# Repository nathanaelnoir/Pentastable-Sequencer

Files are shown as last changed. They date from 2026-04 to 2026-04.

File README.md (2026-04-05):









# Pentastable Sequencer 

# Pentastable Sequencer is a 5-step Eurorack sequencer inspired by the Buchla Sound Easel.

## Contents

- Overview
- Features
- Build & assembly notes
- Testing
- License & contributing

## Overview

This repository contains the KiCad 9 design files for Pentastable Sequencer. The module is built around an `Arduino Nano` with a `TL072` handling the analog output stage. Five pots set the sequence voltages, five LEDs show the active step, `TRIG IN` and `RESET IN` let the module sync to the rack, and `CV OUT` plus `TRIG OUT` bring the sequence back out.

The front panel also carries five step toggles, one `TEMPO` pot for the internal clock, one extra pot in the CV output section, and two center-off mode switches wired as `3st / off / 5st` and `FWD / off / RND_TIE`.

Revision in the KiCad title block is `v1.0`, dated `2026-03-13`.

## Features

- 5-step sequencer built around `Arduino Nano v3.x` and `TL072`.
- Five 10 k step pots: `CV1` to `CV5`.
- Five step LEDs for position indication.
- Internal clock with dedicated `TEMPO` control.
- External `TRIG IN` and `RESET IN`.
- Separate `CV OUT` and `TRIG OUT`.
- Five panel toggles tied to the individual stage outputs: `OUT1` to `OUT5`.
- Center-off mode switches for stage count (`3st` / `5st`) and playback behavior (`FWD` / `RND_TIE`).
- Eurorack power sheet using `+12V`, `-12V`, `+5V`, and `GND` on a 16-pin IDC connector.
- Mixed build with SMD passives and ICs plus through-hole panel hardware.

## Build & assembly notes

- Check `A1` orientation and header alignment before soldering the `Arduino Nano`.
- Check `U1` orientation before soldering the `TL072`.
- Double-check the Eurorack power header orientation before first power-up.
- The panel hardware count is not small: four 3.5 mm jacks, seven potentiometers, seven toggle switches, and five LEDs.
- `SW6` and `SW7` are center-off switches. The schematic note calls this out explicitly because the symbol can look misleading if you read it too quickly.
- The output side uses a buffered CV stage around `U1`, `R7`, `R8`, and the extra panel pot. If you change values there, expect the CV output behavior to change with it.

## Testing

1. Program the `Arduino Nano` with the matching firmware before expecting the module to run. This repository does not include that firmware.
2. Power the module from a current-limited Eurorack supply and verify `+12V`, `-12V`, `+5V`, and `GND` first.
3. Turn the internal `TEMPO` control and confirm the step LEDs advance.
4. Feed a pulse into `TRIG IN` and confirm the sequencer advances from the external trigger.
5. Trigger `RESET IN` and confirm the sequence returns to the first stage.
6. Check `CV OUT` and `TRIG OUT` with a scope or a known-good downstream module.

## License & contributing

No `LICENSE` file has been added to this repository yet. Until that changes, assume the design is shared for reference and not under an explicit open-source license.

$$ \huge \prod_{\star}^5 $$

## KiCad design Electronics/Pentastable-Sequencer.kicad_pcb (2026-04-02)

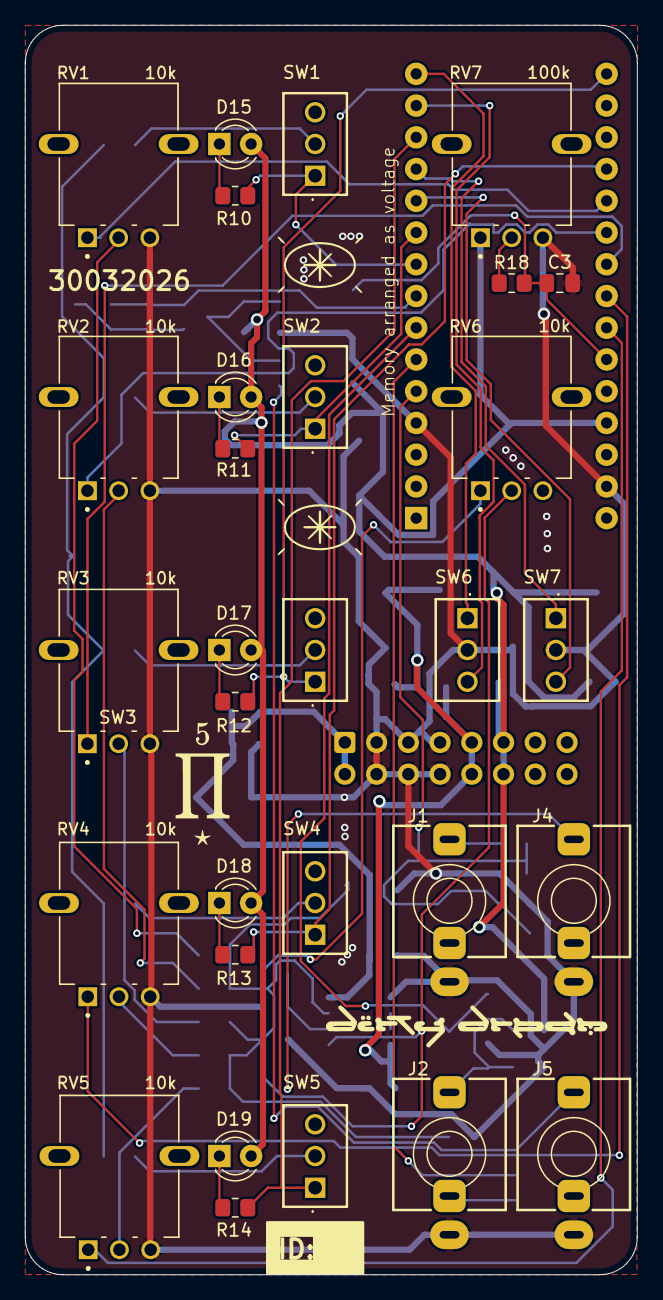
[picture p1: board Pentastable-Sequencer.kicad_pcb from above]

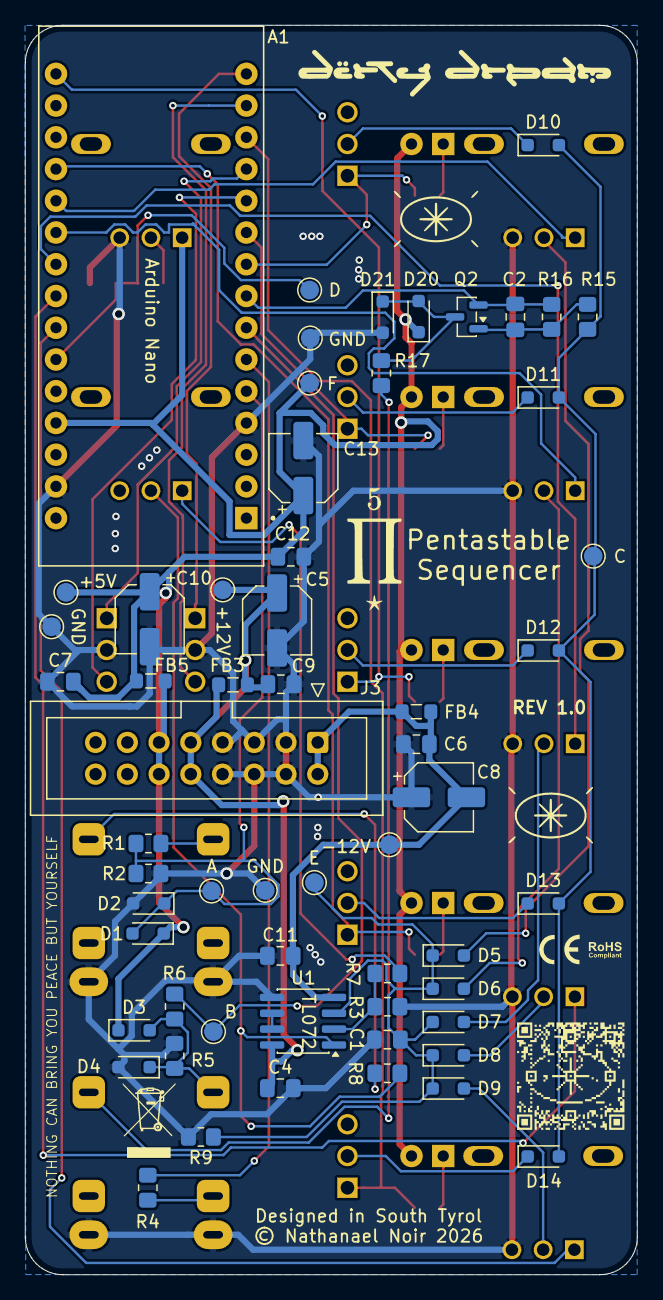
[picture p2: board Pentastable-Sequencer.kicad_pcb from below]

Board: 2 copper layers, 49.0 x 100.0 mm, 87 parts (57 on the bottom side), 52 nets.

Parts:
 : E; TestPoint_Pad_D1.5mm
 #2: C; TestPoint_Pad_D1.5mm
 #3,  #9,  #10: GND; TestPoint_Pad_D1.5mm
 #4: +5V; TestPoint_Pad_D1.5mm
 #5: D; TestPoint_Pad_D1.5mm
 #6: A; TestPoint_Pad_D1.5mm
 #7: F; TestPoint_Pad_D1.5mm
 #8: +12V; TestPoint_Pad_D1.5mm
A1: Arduino Nano; Arduino_Nano
C1: 10nF; C_0805_2012Metric_Pad1.18x1.45mm_HandSolder
C2: 0.22u; C_0805_2012Metric_Pad1.18x1.45mm_HandSolder
C3: 0.1u; C_0805_2012Metric_Pad1.18x1.45mm_HandSolder
C4, C6, C7, C9, C11, C12: 100nF; C_0805_2012Metric_Pad1.18x1.45mm_HandSolder
C5, C8, C10, C13: 10uF; CP_Elec_5x5.4
D1, D2, D3, D4, D20, D21: BAT43; D_SOD-323_HandSoldering
D5, D6, D7, D8, D9, D10, D11, D12, D13, D14: 1N4148; D_SOD-323_HandSoldering
D15: LED 1; LED_D3.0mm_Clear
D16: LED 2; LED_D3.0mm_Clear
D17: LED 3; LED_D3.0mm_Clear
D18: LED 4; LED_D3.0mm_Clear
D19: LED 5; LED_D3.0mm_Clear
FB3, FB4, FB5: FerriteBead_Small; L_0805_2012Metric_Pad1.05x1.20mm_HandSolder
J1: RESET IN; Jack_3.5mm_QingPu_WQP-PJ398SM_Vertical
J2: TRIG IN; Jack_3.5mm_QingPu_WQP-PJ398SM_Vertical
J3: Connector Header; IDC-Header_2x08_P2.54mm_Vertical
J4: CV OUT; Jack_3.5mm_QingPu_WQP-PJ398SM_Vertical
J5: TRIG OUT; Jack_3.5mm_QingPu_WQP-PJ398SM_Vertical
Q2: BC856; SOT-23
R1, R5, R6, R15, R18: 10k; R_0805_2012Metric_Pad1.20x1.40mm_HandSolder
R2, R9: 100k; R_0805_2012Metric_Pad1.20x1.40mm_HandSolder
R3, R7: 4.7k; R_0805_2012Metric_Pad1.20x1.40mm_HandSolder
R4, R16: 2.2k; R_0805_2012Metric_Pad1.20x1.40mm_HandSolder
R8, R17: 1k; R_0805_2012Metric_Pad1.20x1.40mm_HandSolder
R10, R11, R12, R13, R14: 22k; R_0805_2012Metric_Pad1.20x1.40mm_HandSolder
RV1, RV2, RV3, RV4, RV5, RV6: 10k; Potentiometer_Alpha_RD901F_Vertical_Alt
RV7: 100k; Potentiometer_Alpha_RD901F_Vertical_Alt
SW1, SW2, SW3, SW4, SW5, SW6, SW7: SW_SPDT_321; Switch_Toggle_Dailywell_MS1T1B1M2QES_SPDT
U1: TL072; SOIC-8_3.9x4.9mm_P1.27mm

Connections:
3st: A1.14 (D11), SW6.3 (A)
5st: A1.15 (D12), SW6.1 (C)
+5V: #4.1, #7.1, A1.27 (+5V), C7.1, C10.1, C12.1, C13.1, D1.1 (K), D3.1 (K), D15.2 (A), D16.2 (A), D17.2 (A), D18.2 (A), D19.2 (A), D21.1 (K), FB5.1, FB5.2, J3.11, J3.12, RV7.1
+12V: #8.1, C4.1, C5.1, C9.1, FB3.1, FB3.2, J3.9, J3.10, U1.8 (V+)
-12V: C6.2, C8.2, C11.2, FB4.1, FB4.2, J3.1, J3.2, U1.4 (V-)
/JackReset: J1.T, R1.1
/Trigger_DTCT: J2.TN, R4.1
CV1: A1.20 (A1), RV1.1
CV2: A1.21 (A2), RV2.1
CV3: A1.22 (A3), RV3.1
CV4: A1.23 (A4), RV4.1
CV5: A1.24 (A5), RV5.1
FWD: A1.11 (D8), SW7.3 (A)
GND: #3.1, #9.1, #10.1, A1.4 (GND), A1.29 (GND), C1.2, C3.2, C4.2, C5.2, C6.1, C7.2, C8.1, C9.2, C10.2, C11.1, C12.2, C13.2, D2.2 (A), D4.2 (A), D20.2 (A), J1.S, J2.S, J3.3, J3.4, J3.5, J3.6, J3.7, J3.8, J4.S, J5.S, R2.2, R3.2, R5.1, R9.2, RV1.3, RV2.3, RV3.3, RV4.3, RV5.3, RV7.3, SW6.2 (B), SW7.2 (B), U1.5 (+)
unnamed: D3.2 (A), D4.1 (K), J2.T, R5.2, R6.1
unnamed: D5.2 (A), RV1.2
unnamed: .1, C1.1, D5.1 (K), D6.1 (K), D7.1 (K), D8.1 (K), D9.1 (K), R9.1, U1.3 (+)
unnamed: D6.2 (A), RV2.2
unnamed: D7.2 (A), RV3.2
unnamed: D8.2 (A), RV4.2
unnamed: D9.2 (A), RV5.2
unnamed: #2.1, D10.2 (A), D11.2 (A), D12.2 (A), D13.2 (A), D14.2 (A), R15.1
unnamed: D10.1 (K), SW1.2 (B)
unnamed: D11.1 (K), SW2.2 (B)
unnamed: D12.1 (K), SW3.2 (B)
unnamed: D13.1 (K), SW4.2 (B)
unnamed: D14.1 (K), SW5.2 (B)
unnamed: D15.1 (K), R10.1
unnamed: D16.1 (K), R11.1
unnamed: D17.1 (K), R12.1
unnamed: D18.1 (K), R13.1
unnamed: D19.1 (K), R14.1
unnamed: D20.1 (K), D21.2 (A), Q2.3 (C), R17.1
unnamed: J4.T, R8.2
unnamed: J5.T, R17.2
unnamed: C2.2, Q2.1 (B), R15.2, R16.1
unnamed: R7.2, RV6.1
unnamed: R8.1, RV6.2, U1.1
unnamed: R18.1, RV7.2
unnamed: R3.1, R7.1, U1.2 (-)
unnamed: U1.6 (-), U1.7
OUT1: A1.9 (D6), R10.2, SW1.1 (C)
OUT2: A1.10 (D7), R11.2, SW2.1 (C)
OUT3: A1.16 (D13), R12.2, SW3.1 (C)
OUT4: A1.19 (A0), R13.2, SW4.1 (C)
OUT5: A1.13 (D10), R14.2, SW5.1 (C)
RESET IN: #6.1, A1.5 (D2), D1.2 (A), D2.1 (K), R1.2, R2.1
RND_TIE: A1.12 (D9), SW7.1 (C)
TEMPO: #5.1, A1.25 (A6), C3.1, R18.2
TRIGGER DTCT: A1.6 (D3), R4.2
TRIGGER IN: A1.7 (D4), R6.2
TRIGGER OUT: A1.8 (D5), C2.1, Q2.2 (E), R16.2

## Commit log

2026-03-12 first commit message
    [5 Step Sequencer.kicad_pcb, 5 Step Sequencer.kicad_sch, power.kicad_sch]
2026-03-12 feat: rework sequencer switch routing and power sheet
    - add step/output/CV trigger labels and rewired connections
    - replace mode switch with DP3T where needed
    - add power symbols and decoupling parts on the power sheet
    - fix KiCad project metadata and rename the power sheet
    [5 Step Sequencer.kicad_sch, power.kicad_sch]
2026-03-13 feat(kicad): add +5V bulk decoupling and tidy schematic layout
    - add C13 as a 10uF polarized capacitor across +5V and GND
    - add project title/revision metadata and clearer section labels
    - rename the power sheet to "EURORACK POWER"
    - clean up power-sheet wiring, grounding, and text placement
    [5 Step Sequencer.kicad_sch, power.kicad_sch]
2026-03-13 chore(kicad): annotate component values and tidy step-stage wiring
    - replace placeholder resistor, capacitor, and potentiometer values with real part values
    - clean up wire connections around the D10-D14 step-stage diode network
    - adjust symbol and label placement to match the updated routing
    [5 Step Sequencer.kicad_sch]
2026-03-13 Changing Sheet Names
    [5 Step Sequencer.kicad_sch, power.kicad_sch]
2026-03-25 adding some missing footprints
    [5 Step Sequencer.kicad_pcb, 5 Step Sequencer.kicad_sch, power.kicad_sch]
2026-03-25 Changing Toggle Switch Foorptint
    [5 Step Sequencer.kicad_sch, power.kicad_sch]
2026-03-27 adding last missing footprints
    [5 Step Sequencer.kicad_pcb, 5 Step Sequencer.kicad_sch, power.kicad_sch]
2026-03-27 starting pcb layout
    [5 Step Sequencer.kicad_pcb]
2026-03-28 new footprint for tl072
    [5 Step Sequencer.kicad_pcb, 5 Step Sequencer.kicad_sch, power.kicad_sch]
2026-03-29 finalizing tracks, strating silkscreen layout
    [5 Step Sequencer.kicad_pcb]
2026-03-29 silkscreen adjustments
    [5 Step Sequencer.kicad_pcb]
2026-03-29 finishing silkscreen
    [5 Step Sequencer.kicad_pcb]
2026-03-30 • docs: rewrite README for Pentastable Sequencer with badges and KiCad-based module details
2026-04-02 adding new logo, troubleshooting, gerber
    [5 Step Sequencer.kicad_pcb, 5 Step Sequencer.kicad_sch, power.kicad_sch]
2026-04-02 changing folder name
    [5 Step Sequencer.kicad_pcb, 5 Step Sequencer.kicad_sch, power.kicad_sch]
2026-04-02 changing file names
    [Pentastable-Sequencer.kicad_pcb, Pentastable-Sequencer.kicad_sch]

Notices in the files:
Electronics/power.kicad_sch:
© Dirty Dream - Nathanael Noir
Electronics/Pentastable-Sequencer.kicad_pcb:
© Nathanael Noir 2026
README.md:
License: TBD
